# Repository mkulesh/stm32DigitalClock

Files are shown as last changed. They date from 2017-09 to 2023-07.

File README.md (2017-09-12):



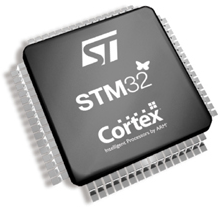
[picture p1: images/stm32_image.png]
#  "A digital clock based on STM32F405 MCU"

This repository provides hardware layout and firmware for a radio-controlled digital clock based on [STM32F405RG](http://www.st.com/content/st_com/en/products/microcontrollers/stm32-32-bit-arm-cortex-mcus/stm32-high-performance-mcus/stm32f4-series/stm32f405-415/stm32f405rg.html) MCU and [DCF77](https://de.wikipedia.org/wiki/DCF77) receiver:
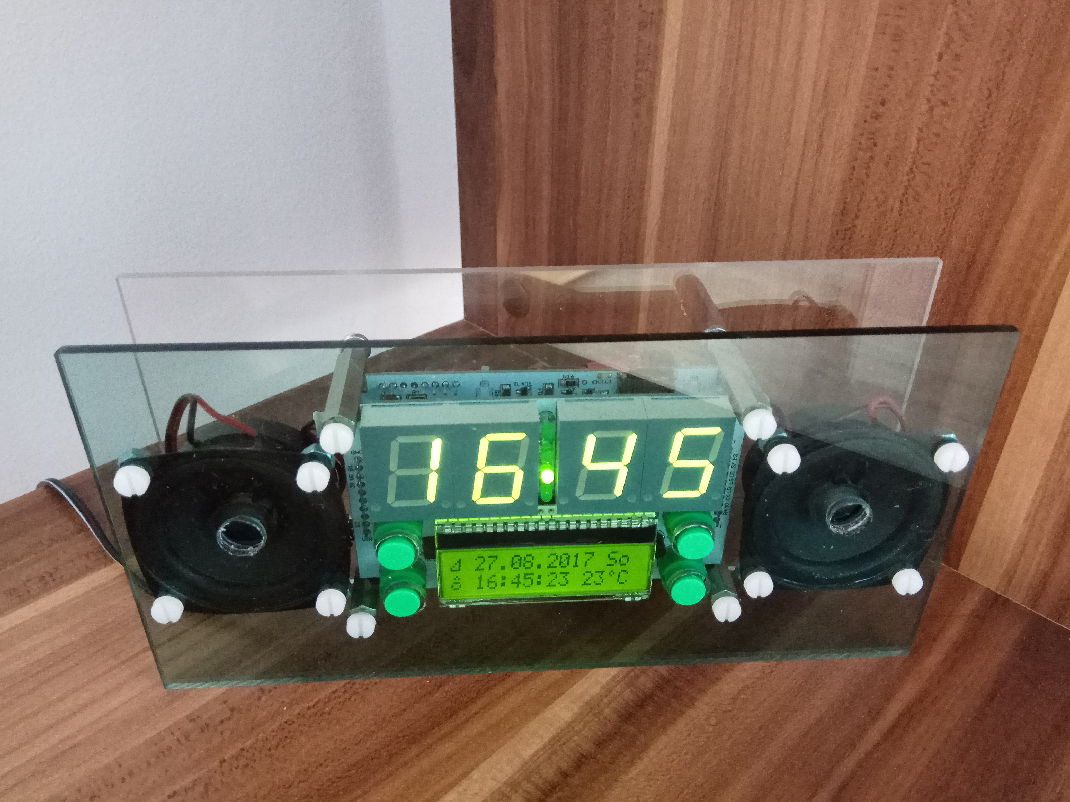
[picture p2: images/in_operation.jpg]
in operation


## Hardware design
This clock consist of two boards:
- the first display board contains four 0.8 inch. single digit numerical displays, one 2x16 chars LCD-display, and four buttons that allow to adjust current time, three alarms and some settings:
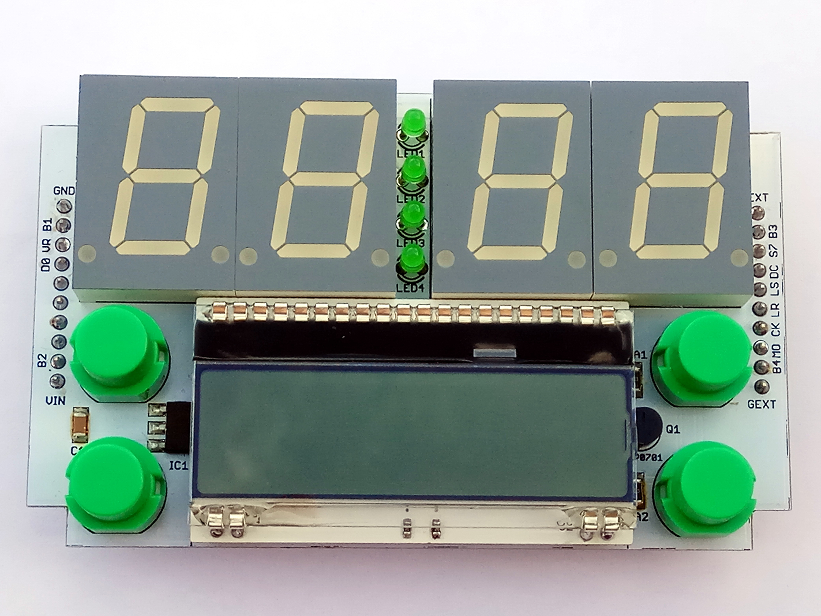
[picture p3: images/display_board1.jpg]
display board


- the second board contains STM32F405 MCU with a lot of periphery: DC connector, voltage regulators, HSE and LSE crystals, JTAG programming connector, light sensor, temperature sensor, DCF77 receiver with ferrite core, SD card connector, DAC and audio amplifier for primary WAV-based alarm, outputs for audio speakers, one piezo buzzer for the secondary alarm, UART-USB bridge and USB connector (used for debugging purposes):
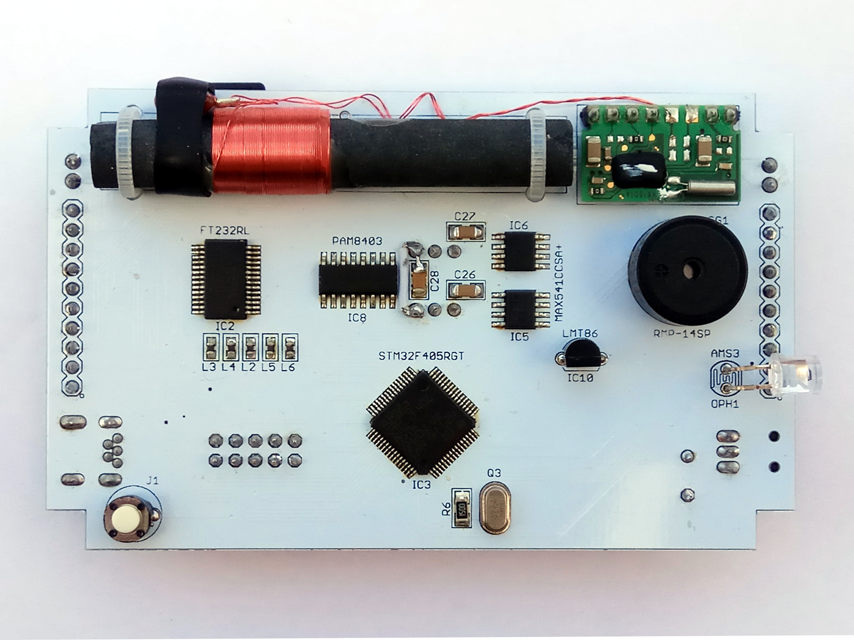
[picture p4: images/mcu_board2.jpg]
mcu board


PCB are developed in Eagle CAD (see directory pcb):
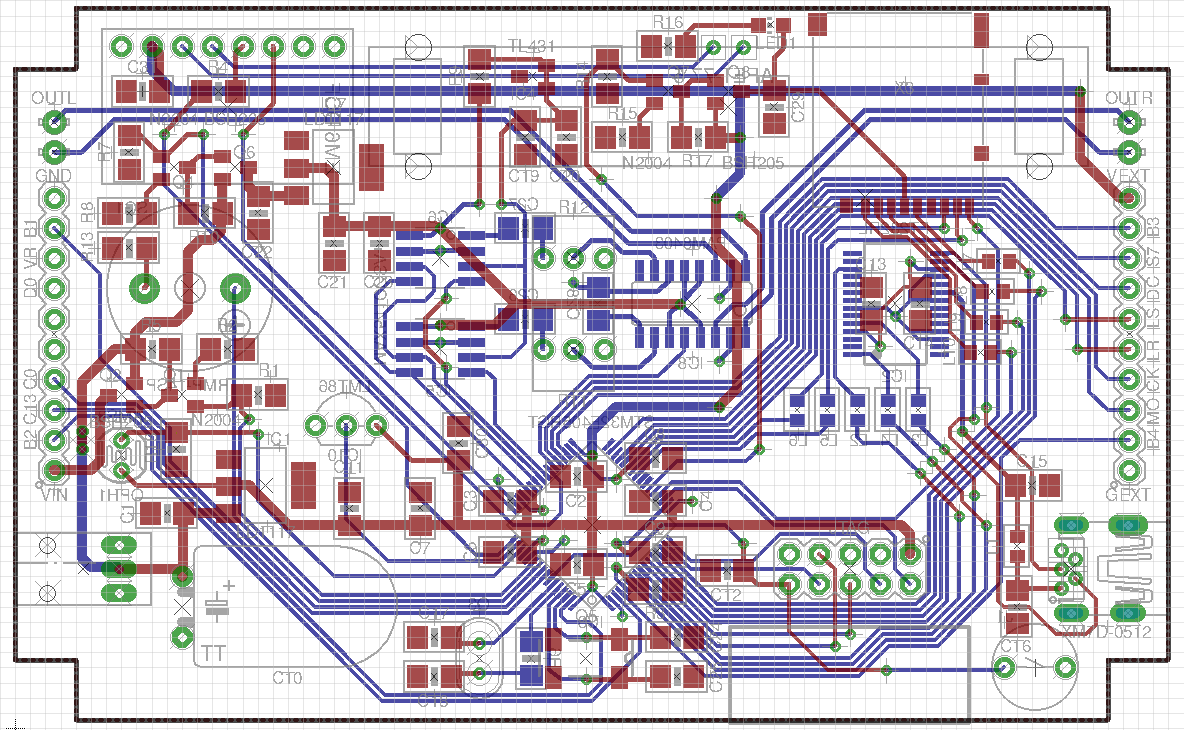
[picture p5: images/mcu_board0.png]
mcu board layout

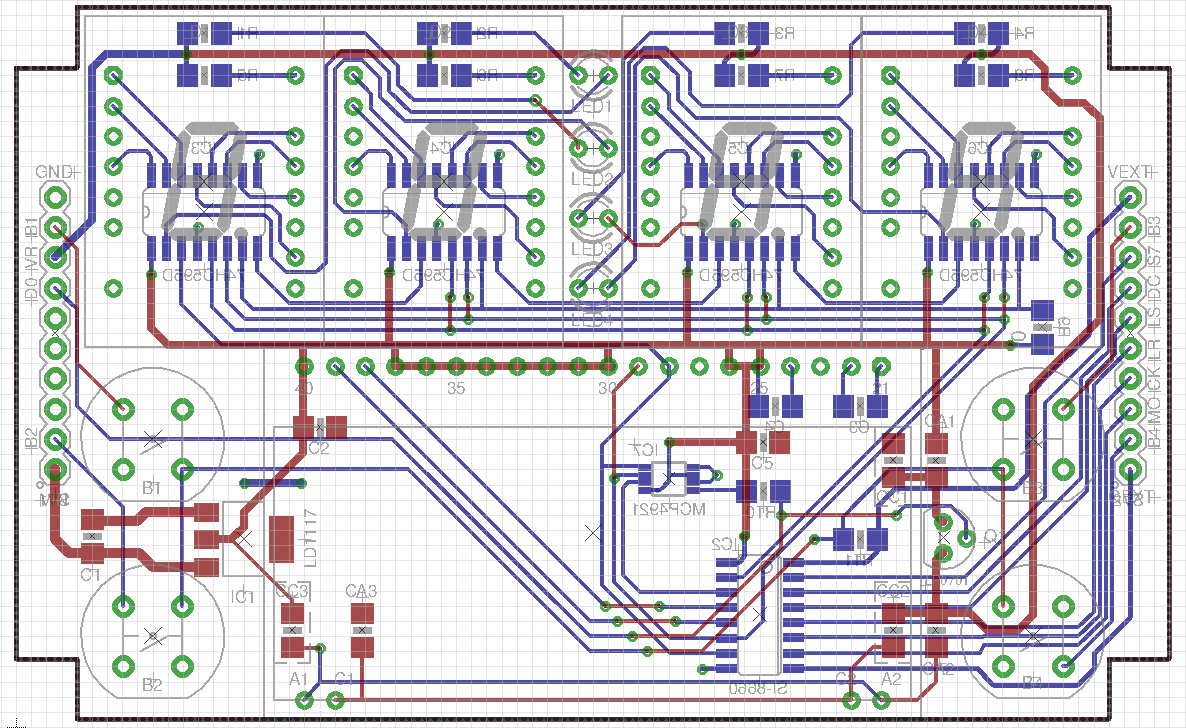
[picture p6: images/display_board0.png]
display board layout


## Firmware
The firmware (see directory src) is written in C++ [System Workbench for STM32](http://www.st.com/en/development-tools/sw4stm32.html). It is based on HAL library, FatFS and the second object-oriented abstraction layer called *StmPlusPlus* that implements high-level access for all used hardware components. *StmPlusPlus* also contains WAV-streamer (16 bit stereo, 44kHz) and [DCF77](https://de.wikipedia.org/wiki/DCF77) receiver with a special windowed filter used to improce signal quality.

## There are some known problems in this project
- DCF77 receiver heeds some time a pair of hours to capture the time stamp. 
- Wrong position of the DC and USB connector: access to the connector is blocked by audio speakers
- Level of the input signal for the audio amplifier is too high. 

## License
This software is published under the *GNU General Public License, Version 3*

Copyright (C) 2016-2017 Mikhail Kulesh

This program is free software: you can redistribute it and/or modify it under the terms of the GNU General Public License as published by the Free Software Foundation, either version 3 of the License, or (at your option) any later version.

This program is distributed in the hope that it will be useful, but WITHOUT ANY WARRANTY; without even the implied warranty of MERCHANTABILITY or FITNESS FOR A PARTICULAR PURPOSE.  See the GNU General Public License for more details. You should have received a copy of the GNU General Public License along with this program.

If not, see [www.gnu.org/licenses](http://www.gnu.org/licenses).

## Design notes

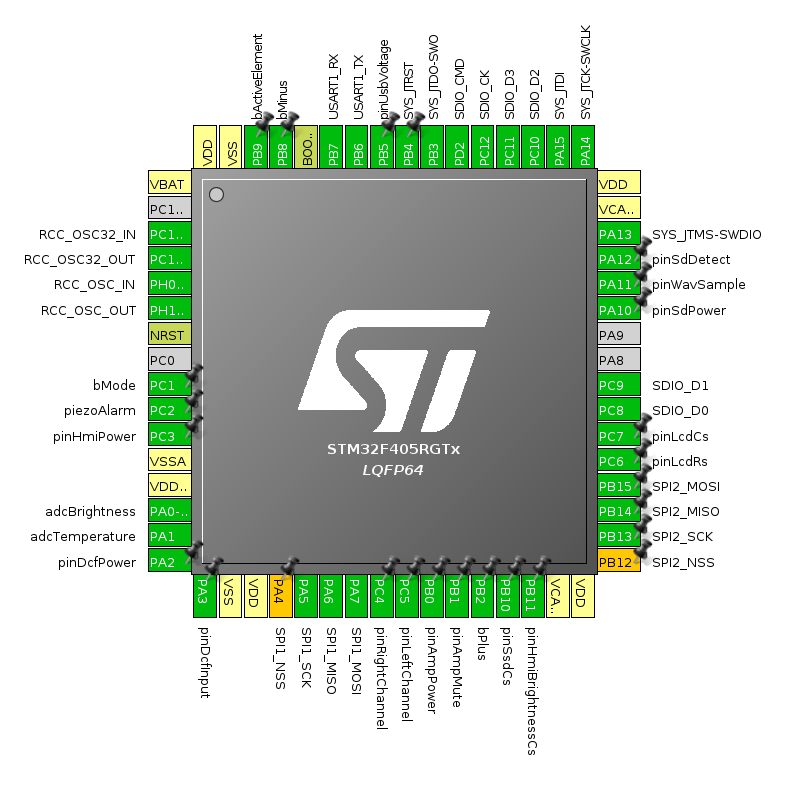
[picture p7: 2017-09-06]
images/mcu_pinout.png

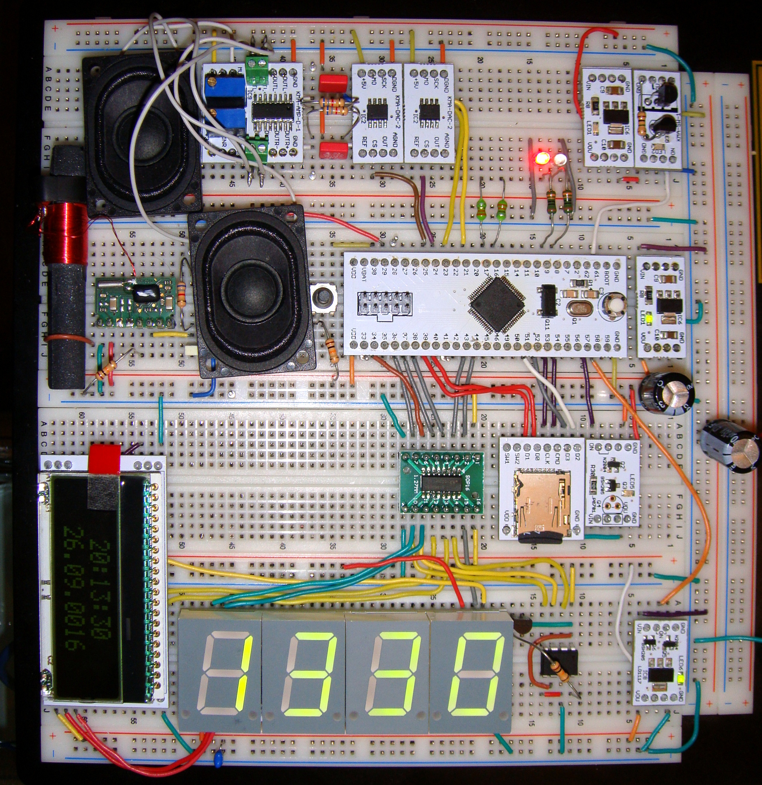
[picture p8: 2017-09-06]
images/prototype1.jpg

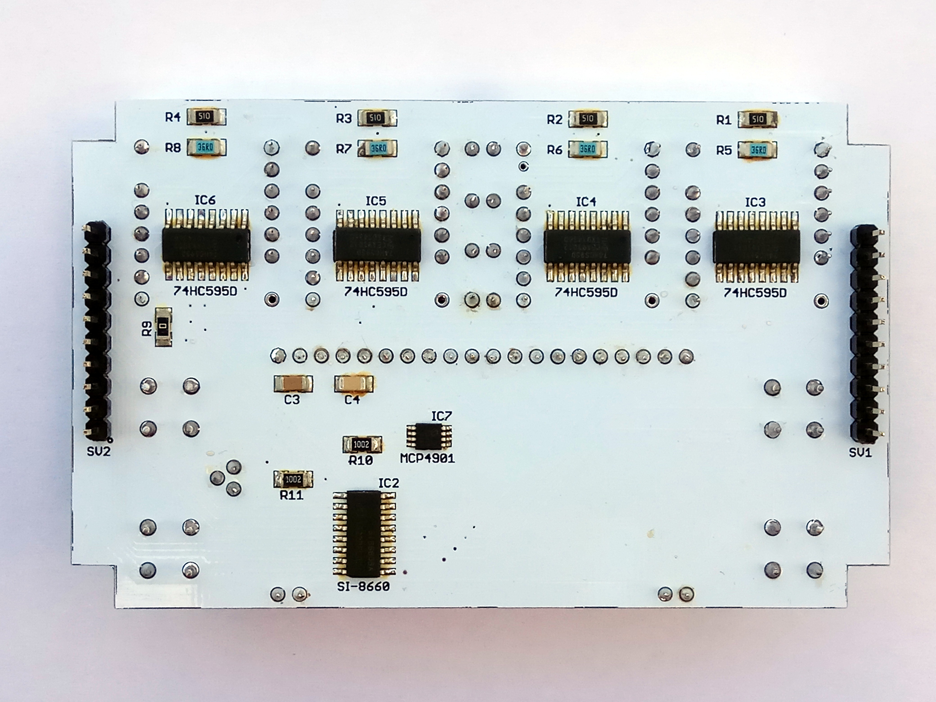
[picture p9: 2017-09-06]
images/display_board2.jpg

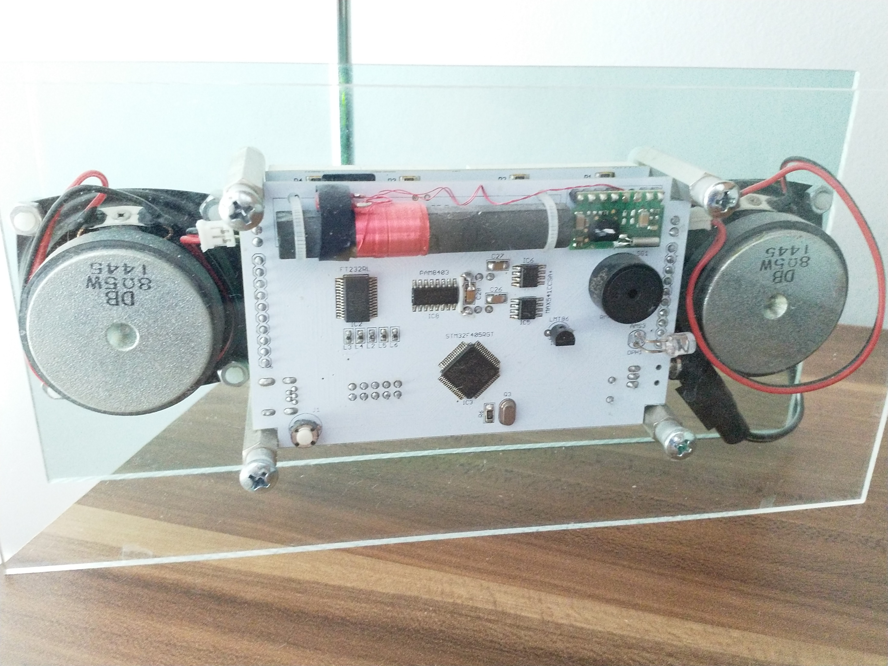
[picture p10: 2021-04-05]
images/back_view.jpg

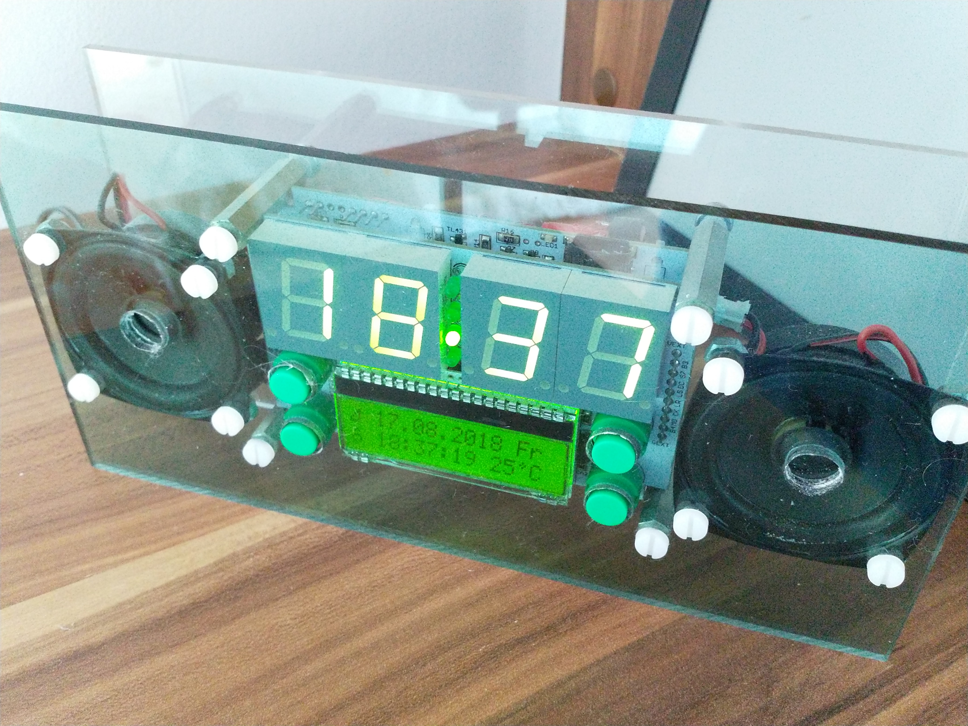
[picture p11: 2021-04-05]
images/front_view.jpg

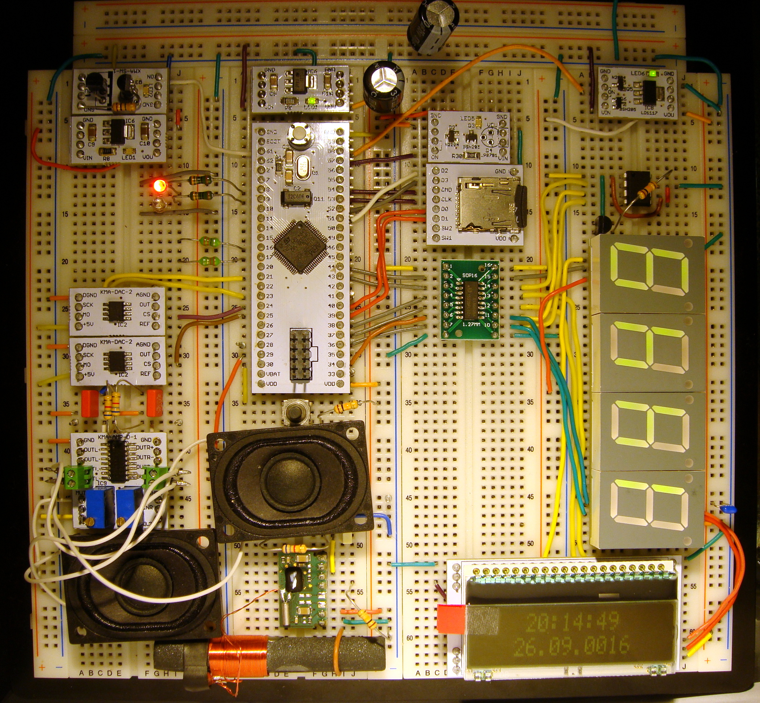
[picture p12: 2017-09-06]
images/prototype2.jpg

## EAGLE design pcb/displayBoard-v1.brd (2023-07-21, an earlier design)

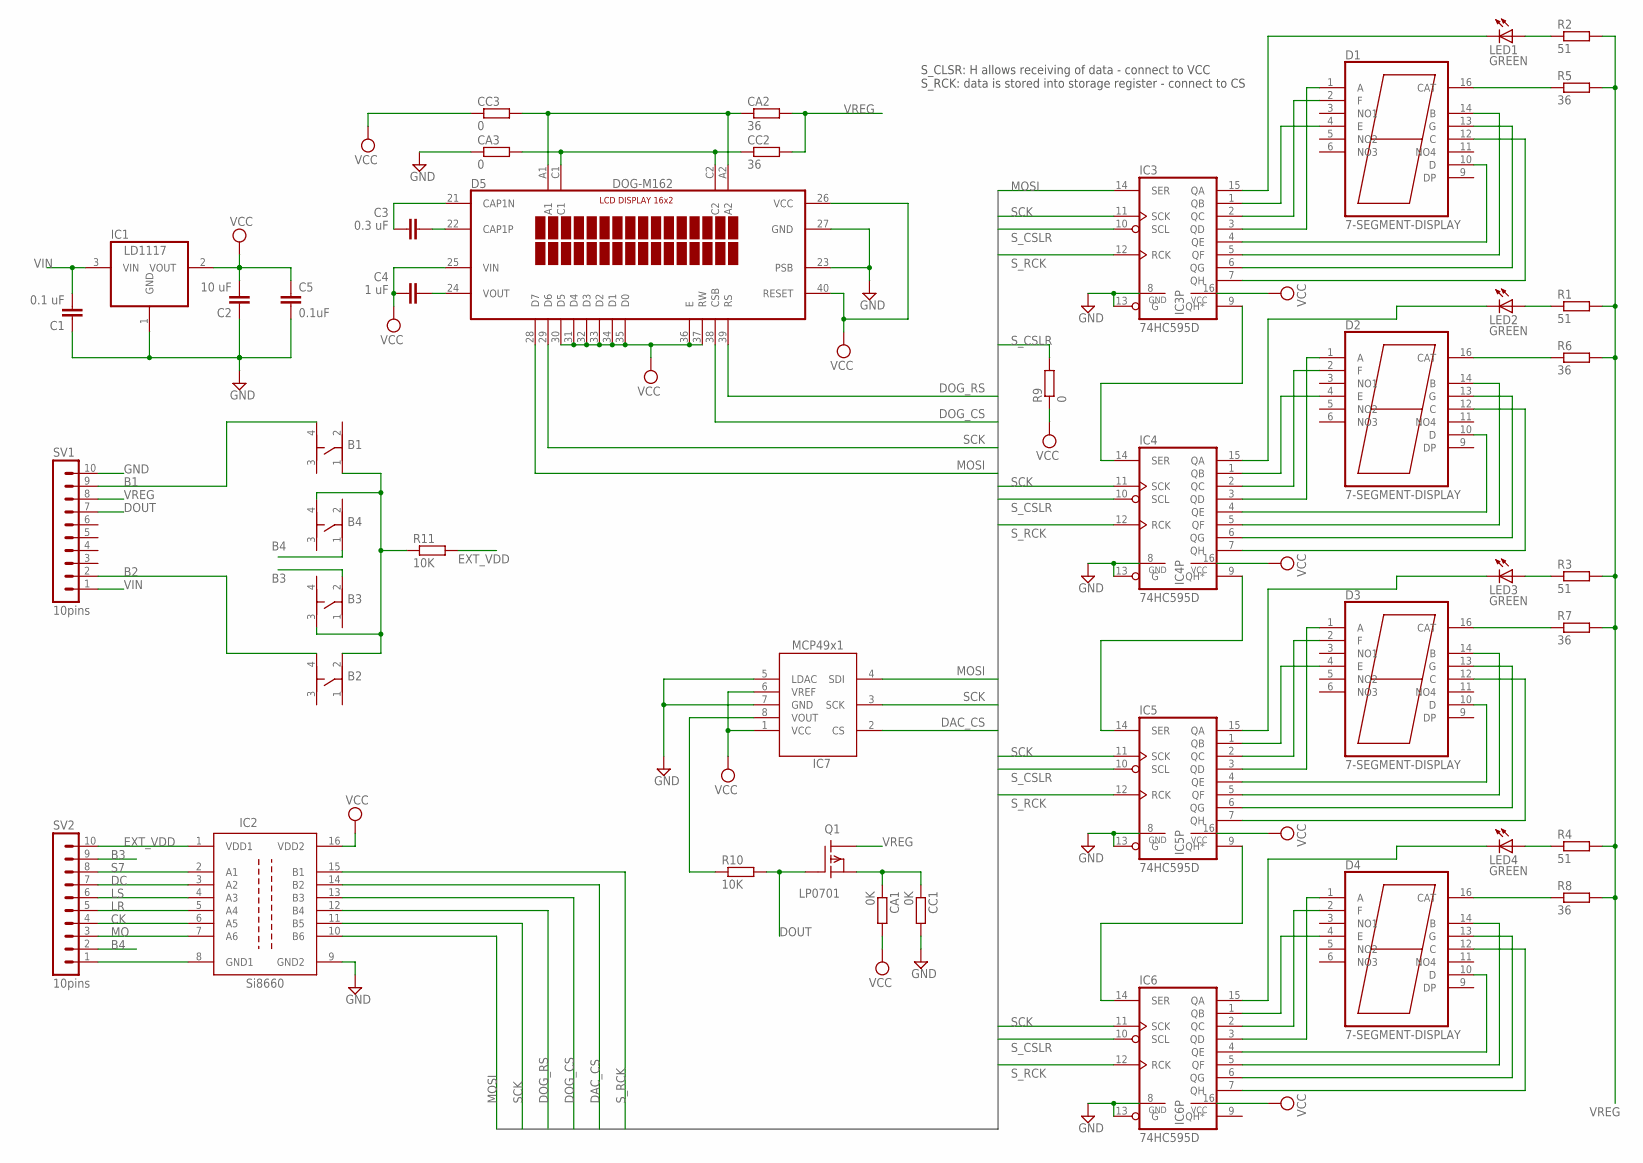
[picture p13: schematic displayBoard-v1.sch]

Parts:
B1, B2, B3, B4: BUTTON-D6X
C1: 0.1 uF; C1206
C2: 10 uF; C1206
C3: 0.3 uF; C1206
C4: 1 uF; C1206
C5: 0.1uF; C1206
CA1: 0K; R1206
CA2: 36; R1206
CA3: 0; R1206
CC1: 0K; R1206
CC2: 36; R1206
CC3: 0; R1206
D1, D2, D3, D4: 7-SEGMENT-DISPLAY; LDS-A812
D5: DOG-M162; DOGM162
IC1: LD1117; SOT223
IC2: SI-8660; SOP-16
IC3, IC4, IC5, IC6: 74HC595D; SO16
IC7: MCP4921; MSOP-8
LED1, LED2, LED3, LED4: GREEN; LED3MM
Q1: LP0701; TO-92
R1, R2, R3, R4: 51; R1206
R5, R6, R7, R8: 36; R1206
R9: 0; R1206
R10, R11: 10K; R1206
SV1, SV2: 10pins; MA10-1

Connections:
B1: B1.4, SV1.9
B2: B2.4, SV1.2
B3: B3.2, SV2.9
B4: B4.1, SV2.2
CK: IC2.6 (A5), SV2.4
DAC_CS: IC2.14 (B2), IC7.2 (CS)
DC: IC2.3 (A2), SV2.7
DOG_CS: D5.38 (CSB), IC2.13 (B3)
DOG_RS: D5.39 (RS), IC2.12 (B4)
DOUT: Q1.2 (G), R10.2, SV1.7
EXT_VDD: IC2.1 (VDD1), R11.2, SV2.10
GND: C1.1, C2.1, C5.2, CA3.1, CC1.2, D5.23 (PSB), D5.27 (GND), IC1.1 (GND), IC2.9 (GND2), IC3.8 (GND), IC3.13 (G), IC4.8 (GND), IC4.13 (G), IC5.8 (GND), IC5.13 (G), IC6.8 (GND), IC6.13 (G), IC7.5 (LDAC), IC7.7 (GND), SV1.10
LR: IC2.5 (A4), SV2.5
LS: IC2.4 (A3), SV2.6
MO: IC2.7 (A6), SV2.3
MOSI: D5.28 (D7), IC2.10 (B6), IC3.14 (SER), IC7.4 (SDI)
unnamed: D1.12 (C), IC3.7 (QH)
unnamed: D2.4 (E), IC4.1 (QB)
unnamed: D2.1 (A), IC4.3 (QD)
unnamed: D2.10 (D), IC4.4 (QE)
unnamed: D2.13 (G), IC4.6 (QG)
unnamed: D3.4 (E), IC5.1 (QB)
unnamed: D3.2 (F), IC5.2 (QC)
unnamed: D3.1 (A), IC5.3 (QD)
unnamed: D3.13 (G), IC5.6 (QG)
unnamed: D3.12 (C), IC5.7 (QH)
unnamed: D4.4 (E), IC6.1 (QB)
unnamed: IC2.8 (GND1), SV2.1
unnamed: B1.1, B2.2, B3.3, B4.4, R11.1
unnamed: LED4.A, R4.1
unnamed: LED3.A, R3.1
unnamed: IC6.15 (QA), LED4.K (C)
unnamed: IC7.8 (VOUT), R10.1
unnamed: IC5.15 (QA), LED3.K (C)
unnamed: IC4.15 (QA), LED2.K (C)
unnamed: D1.4 (E), IC3.1 (QB)
unnamed: D1.2 (F), IC3.2 (QC)
unnamed: LED2.A, R1.1
unnamed: D1.1 (A), IC3.3 (QD)
unnamed: D1.10 (D), IC3.4 (QE)
unnamed: D1.14 (B), IC3.5 (QF)
unnamed: D1.13 (G), IC3.6 (QG)
unnamed: D2.2 (F), IC4.2 (QC)
unnamed: D2.14 (B), IC4.5 (QF)
unnamed: D2.12 (C), IC4.7 (QH)
unnamed: IC3.9 (QH*), IC4.14 (SER)
unnamed: D3.10 (D), IC5.4 (QE)
unnamed: D3.14 (B), IC5.5 (QF)
unnamed: D4.2 (F), IC6.2 (QC)
unnamed: D4.1 (A), IC6.3 (QD)
unnamed: D4.10 (D), IC6.4 (QE)
unnamed: D4.14 (B), IC6.5 (QF)
unnamed: D4.13 (G), IC6.6 (QG)
unnamed: D4.12 (C), IC6.7 (QH)
unnamed: IC5.9 (QH*), IC6.14 (SER)
unnamed: IC4.9 (QH*), IC5.14 (SER)
unnamed: D1.16 (CAT), R5.1
unnamed: D2.16 (CAT), R6.1
unnamed: D3.16 (CAT), R7.1
unnamed: D4.16 (CAT), R8.1
unnamed: IC3.15 (QA), LED1.K (C)
unnamed: LED1.A, R2.1
unnamed: CA1.1, CC1.1, Q1.1 (S)
unnamed: CA2.1, CC3.2, D5.A1, D5.A2
unnamed: C3.1, D5.21 (CAP1N)
unnamed: C3.2, D5.22 (CAP1P)
unnamed: C4.1, D5.24 (VOUT)
unnamed: CA3.2, CC2.1, D5.C1, D5.C2
S7: IC2.2 (A1), SV2.8
SCK: D5.29 (D6), IC2.11 (B5), IC3.11 (SCK), IC4.11 (SCK), IC5.11 (SCK), IC6.11 (SCK), IC7.3 (SCK)
S_CSLR: IC3.10 (SCL), IC4.10 (SCL), IC5.10 (SCL), IC6.10 (SCL), R9.2
S_RCK: IC2.15 (B1), IC3.12 (RCK), IC4.12 (RCK), IC5.12 (RCK), IC6.12 (RCK)
VCC: C2.2, C4.2, C5.1, CA1.2, CC3.1, D5.25 (VIN), D5.26 (VCC), D5.30 (D5), D5.31 (D4), D5.32 (D3), D5.33 (D2), D5.34 (D1), D5.35 (D0), D5.36 (E), D5.37 (RW), D5.40 (RESET), IC1.2 (VOUT), IC2.16 (VDD2), IC3.16 (VCC), IC4.16 (VCC), IC5.16 (VCC), IC6.16 (VCC), IC7.1 (VCC), IC7.6 (VREF), R9.1
VIN: C1.2, IC1.3 (VIN), SV1.1
VREG: CA2.2, CC2.2, Q1.3 (D), R1.2, R2.2, R3.2, R4.2, R5.2, R6.2, R7.2, R8.2, SV1.8

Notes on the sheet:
S_CLSR: H allows receiving of data - connect to VCC S_RCK: data is stored into storage register - connect to CS

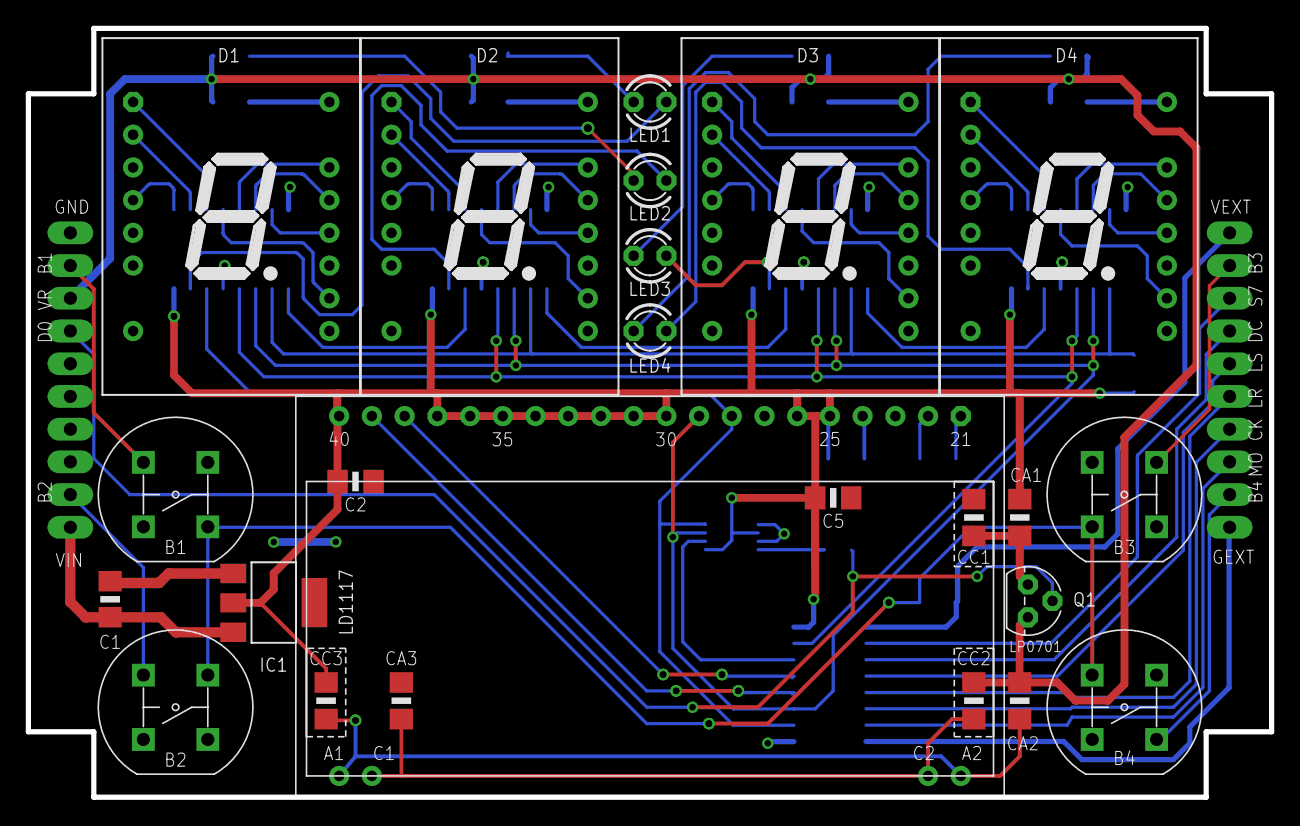
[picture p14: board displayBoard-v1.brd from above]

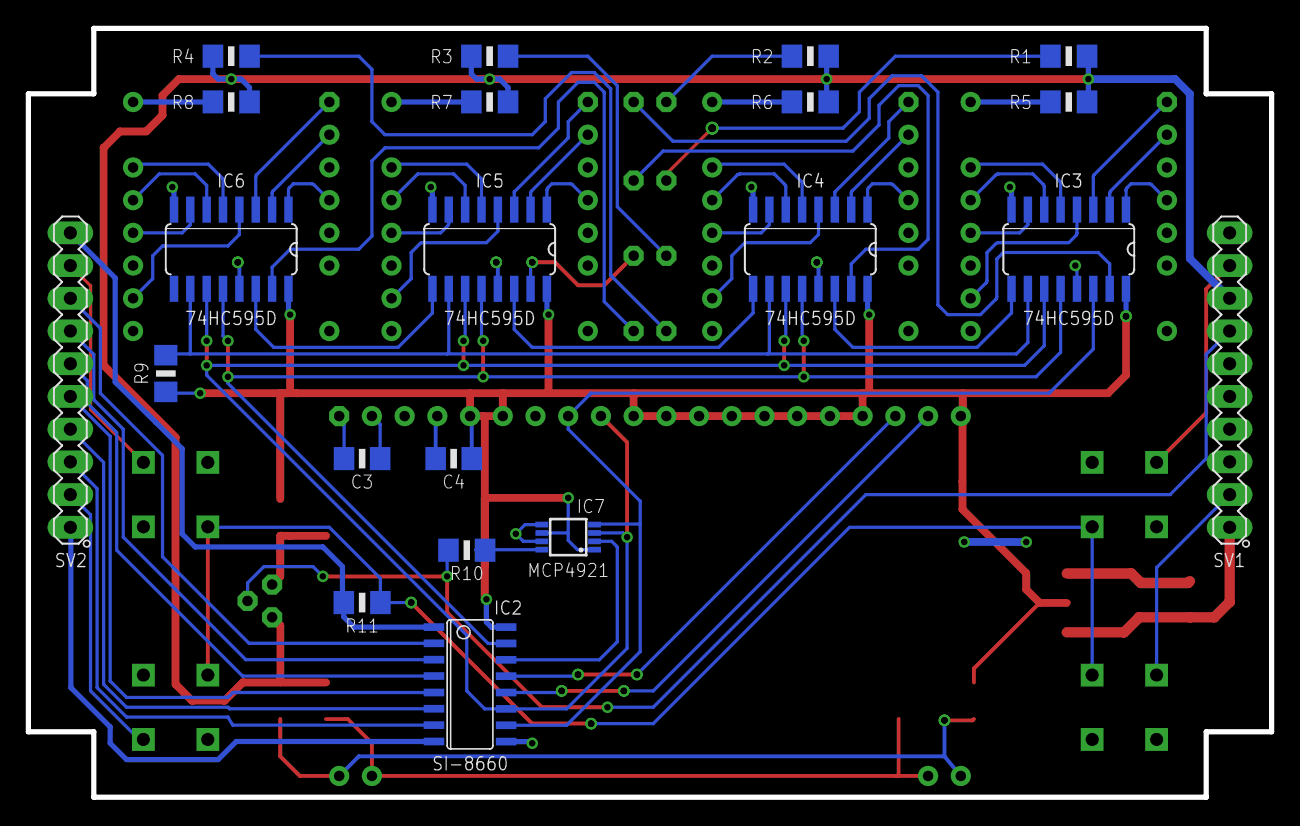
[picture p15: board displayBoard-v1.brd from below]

Board: 2 copper layers, 96.5 x 59.7 mm, 45 parts (21 on the bottom side), 75 nets.

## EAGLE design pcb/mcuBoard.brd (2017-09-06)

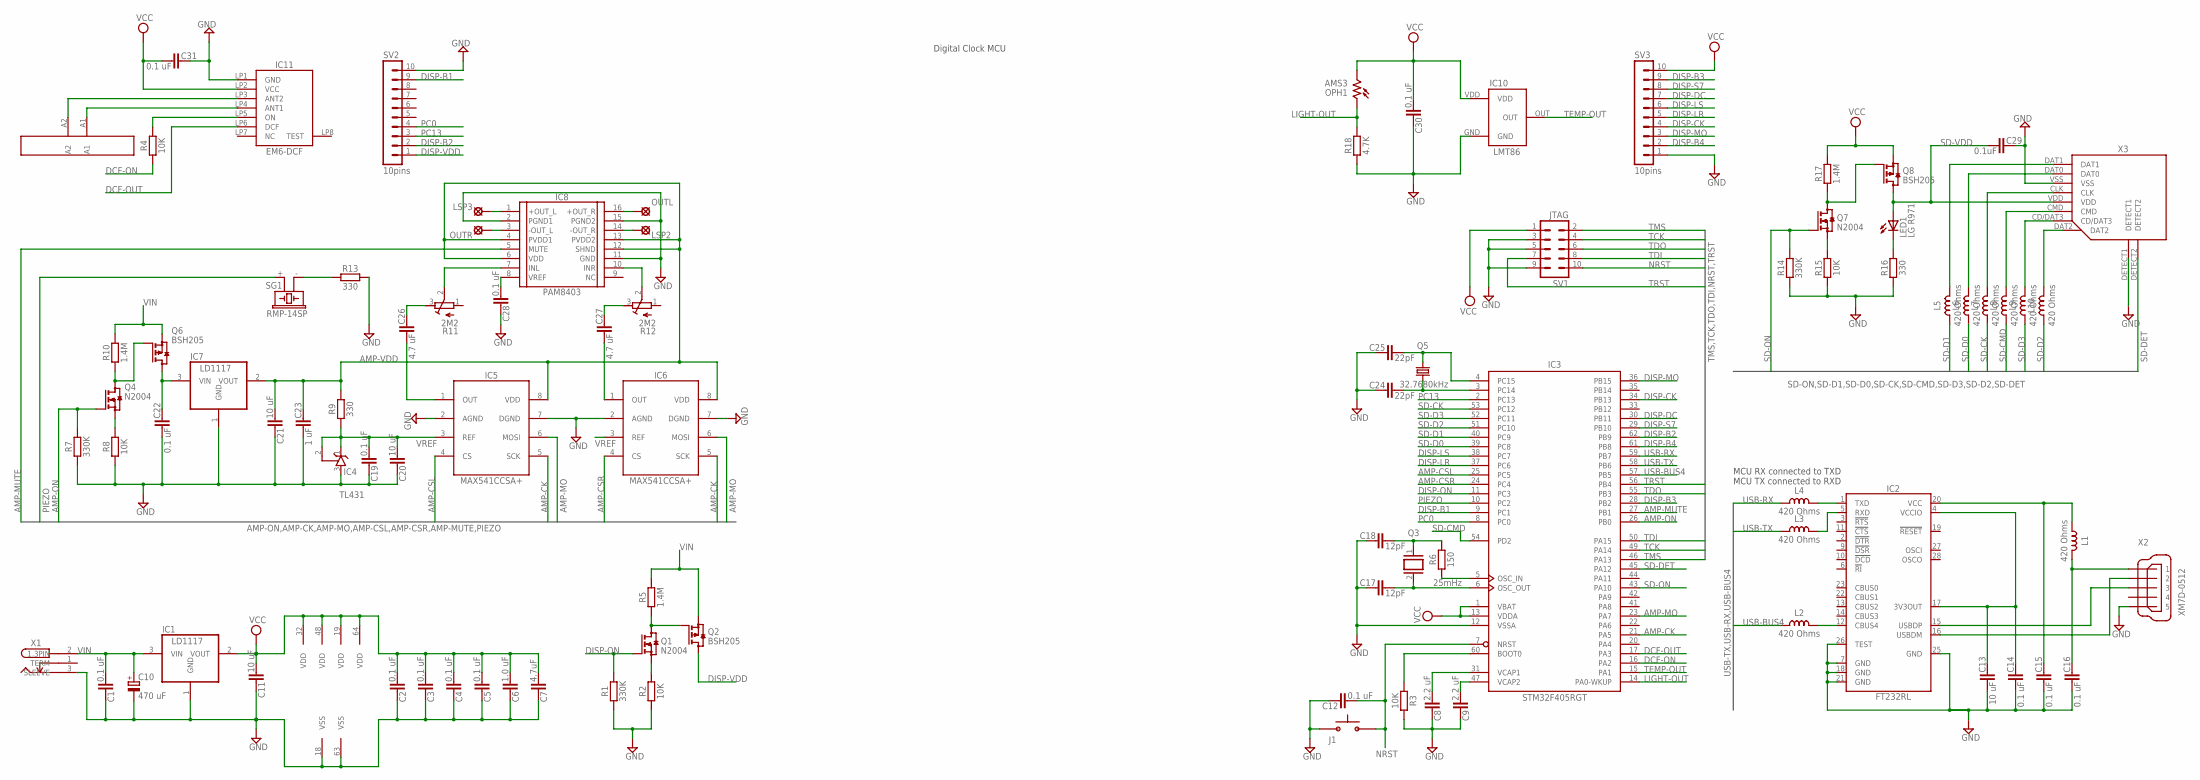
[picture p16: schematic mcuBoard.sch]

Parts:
A1: DCF77-ANT
C1, C2, C3, C4, C5, C12, C14, C15, C16, C19, C22, C28, C30, C31: 0.1 uF; C1206
C6: 1.0 uF; C1206
C7: 4.7uF; C1206
C8, C9: 2.2 uF; C1206
C10: 470 uF; TT5D11L
C11, C13, C20, C21: 10 uF; C1206
C17, C18: 12pF; C1206
C23: 1 uF; C1206
C24, C25: 22pF; C1206
C26, C27: 4.7 uF; C1206
C29: 0.1uF; C1206
IC1, IC7: LD1117; SOT223
IC2: FT232RL; SSOP28
IC3: STM32F405RGT; LQFP64
IC4: TL431; SOT-23
IC5, IC6: MAX541CCSA+; SOIC-8
IC8: PAM8403; SOP-16
IC10: LMT86
IC11: DCF77
J1: BUTTON-FSM14JRT
L1, L2, L3, L4, L5, L6, L7, L8, L9, L10: 420 Ohms; L0603
LED1: LG R971; CHIP-LED0805
LSP2, LSP3: LSP10
OPH1: AMS3; VT900
OUTL: LSP10
OUTR: LSP10
Q1, Q4, Q7: N2004; SOT23
Q2, Q6, Q8: BSH205; SOT23
Q3: 25mHz; HC-46X
Q5: 32.7680kHz; MC-306
R1, R7, R14: 330K; R1206
R2, R3, R4, R8, R15: 10K; R1206
R5, R10, R17: 1.4M; R1206
R6: 150; R1206
R9, R13, R16: 330; R1206
R11, R12: 2M2; R-TRIM-3362U
R18: 4.7K; R1206
SG1: RMP-14SP; F/CM12P
SV1: JTAG; MA05-2
SV2, SV3: 10pins; MA10-1
X1: DC-8N; BUCHSE-1.3X3.75
X2: XM7D-0512
X3: MICRO-SD-DM3AT; DM3AT

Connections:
AMP-CK: IC3.21 (PA5), IC5.5 (SCK), IC6.5 (SCK)
AMP-CSL: IC3.25 (PC5), IC5.4 (CS)
AMP-CSR: IC3.24 (PC4), IC6.4 (CS)
AMP-MO: IC3.23 (PA7), IC5.6 (MOSI), IC6.6 (MOSI)
AMP-MUTE: IC3.27 (PB1), IC8.5 (MUTE)
AMP-ON: IC3.26 (PB0), Q4.1 (G), R7.2
AMP-VDD: C21.2, C23.1, IC5.8 (VDD), IC6.8 (VDD), IC7.2 (VOUT), IC8.4 (PVDD1), IC8.6 (VDD), IC8.12 (SHND), IC8.13 (PVDD2), R9.2
BOOT: IC3.60 (BOOT0), R3.1
DAC_OUTR: C27.2, IC6.1 (OUT)
DCF-ON: IC3.16 (PA2), R4.1
DCF-OUT: IC3.17 (PA3), IC11.LP6 (DCF)
DISP-B1: IC3.9 (PC1), SV2.9
DISP-B2: IC3.62 (PB9), SV2.2
DISP-B3: IC3.28 (PB2), SV3.9
DISP-B4: IC3.61 (PB8), SV3.2
DISP-CK: IC3.34 (PB13), SV3.4
DISP-DC: IC3.30 (PB11), SV3.7
DISP-LR: IC3.37 (PC6), SV3.5
DISP-LS: IC3.38 (PC7), SV3.6
DISP-MO: IC3.36 (PB15), SV3.3
DISP-ON: IC3.11 (PC3), Q1.1 (G), R1.2
DISP-S7: IC3.29 (PB10), SV3.8
DISP-VDD: Q2.3 (D), SV2.1
D_VG: Q7.3 (D), Q8.1 (G), R17.1
D_VG1: Q4.3 (D), Q6.1 (G), R10.1
D_VG2: Q1.3 (D), Q2.1 (G), R5.1
GND: C1.1, C2.1, C3.1, C4.1, C5.1, C6.1, C7.1, C8.1, C9.1, C10.-, C11.1, C12.1, C13.2, C14.2, C15.2, C16.2, C17.1, C18.1, C19.1, C20.1, C21.1, C22.2, C23.2, C24.1, C25.1, C28.1, C29.1, C30.1, C31.1, IC1.1 (GND), IC2.7 (GND), IC2.18 (GND), IC2.21 (GND), IC2.25 (GND), IC2.26 (TEST), IC3.12 (VSSA), IC3.18 (VSS), IC3.63 (VSS), IC4.3 (A), IC5.2 (AGND), IC5.7 (DGND), IC6.2 (AGND), IC6.7 (DGND), IC7.1 (GND), IC8.2 (PGND1), IC8.11 (GND), IC8.15 (PGND2), IC10.GND, IC11.LP1 (GND), J1.P$1 (1), R1.1, R2.1, R3.2, R7.1, R8.1, R13.2, R14.1, R15.1, R16.1, R18.1, SV1.3, SV1.5, SV1.9, SV2.10, SV3.1, X1.3 (SLEEVE), X2.5, X3.DETECT1, X3.VSS
LIGHT-OUT: IC3.14 (PA0-WKUP), OPH1.1, R18.2
unnamed: IC3.5 (OSC_IN), R6.1
unnamed: A1.A1, IC11.LP4 (ANT1)
unnamed: A1.A2, IC11.LP3 (ANT2)
unnamed: L10.2, X3.DAT2
unnamed: L9.2, X3.CD/DAT3
unnamed: L8.2, X3.CMD
unnamed: L7.2, X3.CLK
unnamed: L6.2, X3.DAT0
unnamed: L5.2, X3.DAT1
unnamed: Q4.2 (S), R8.2
unnamed: C26.2, IC5.1 (OUT)
unnamed: IC8.16 (+OUT_R), OUTL.MP
unnamed: C26.1, R11.3
unnamed: C28.2, IC8.8 (VREF)
unnamed: C27.1, R12.3
unnamed: R13.1, SG1.- (2)
unnamed: C22.1, IC7.3 (VIN), Q6.3 (D)
unnamed: C16.1, L1.2, X2.1
unnamed: C15.1, IC2.20 (VCC), L1.1
unnamed: C13.1, C14.1, IC2.4 (VCCIO), IC2.17 (3V3OUT)
unnamed: IC2.16 (USBDM), X2.2
unnamed: IC2.15 (USBDP), X2.3
unnamed: IC2.1 (TXD), L4.2
unnamed: IC2.5 (RXD), L3.2
unnamed: IC2.12 (CBUS4), L2.1
unnamed: Q1.2 (S), R2.2
unnamed: C18.2, Q3.1, R6.2
unnamed: C17.2, IC3.6 (OSC_OUT), Q3.2
unnamed: IC11.LP5 (ON), R4.2
unnamed: LED1.C, R16.2
unnamed: Q7.2 (S), R15.2
unnamed: IC8.1 (+OUT_L), LSP3.MP
unnamed: IC8.3 (-OUT_L), OUTR.MP
unnamed: IC8.14 (-OUT_R), LSP2.MP
unnamed: IC8.7 (INL), R11.2
unnamed: IC8.10 (INR), R12.2
NRST: C12.2, IC3.7 (NRST), J1.P$2 (2), SV1.10
PC0: IC3.8 (PC0), SV2.4
PC13: IC3.2 (PC13), SV2.3
PIEZO: IC3.10 (PC2), SG1.+ (1)
Q2M: C24.2, IC3.3 (PC14), Q5.1
Q2P: C25.2, IC3.4 (PC15), Q5.4 (2)
SD-CK: IC3.53 (PC12), L7.1
SD-CMD: IC3.54 (PD2), L8.1
SD-D0: IC3.39 (PC8), L6.1
SD-D1: IC3.40 (PC9), L5.1
SD-D2: IC3.51 (PC10), L10.1
SD-D3: IC3.52 (PC11), L9.1
SD-DET: IC3.45 (PA12), X3.DETECT2
SD-ON: IC3.43 (PA10), Q7.1 (G), R14.2
SD-VDD: C29.2, LED1.A, Q8.3 (D), X3.VDD
TCK: IC3.49 (PA14), SV1.4
TDI: IC3.50 (PA15), SV1.8
TDO: IC3.55 (PB3), SV1.6
TEMP-OUT: IC3.15 (PA1), IC10.OUT
TMS: IC3.46 (PA13), SV1.2
TRST: IC3.56 (PB4), SV1.7
USB-BUS4: IC3.57 (PB5), L2.2
USB-RX: IC3.59 (PB7), L4.1
USB-TX: IC3.58 (PB6), L3.1
VCAP1: C8.2, IC3.31 (VCAP1)
VCAP2: C9.2, IC3.47 (VCAP2)
VCC: C2.2, C3.2, C4.2, C5.2, C6.2, C7.2, C11.2, C30.2, C31.2, IC1.2 (VOUT), IC3.1 (VBAT), IC3.13 (VDDA), IC3.19 (VDD), IC3.32 (VDD), IC3.48 (VDD), IC3.64 (VDD), IC10.VDD, IC11.LP2 (VCC), OPH1.2, Q8.2 (S), R17.2, SV1.1, SV3.10
VIN: C1.2, C10.+, IC1.3 (VIN), Q2.2 (S), Q6.2 (S), R5.2, R10.2, X1.2 (1.3PIN)
VREF: C19.2, C20.2, IC4.1 (C), IC4.2 (R), IC5.3 (REF), IC6.3 (REF), R9.1

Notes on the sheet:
MCU RX connected to TXD MCU TX connected to RXD
Digital Clock MCU

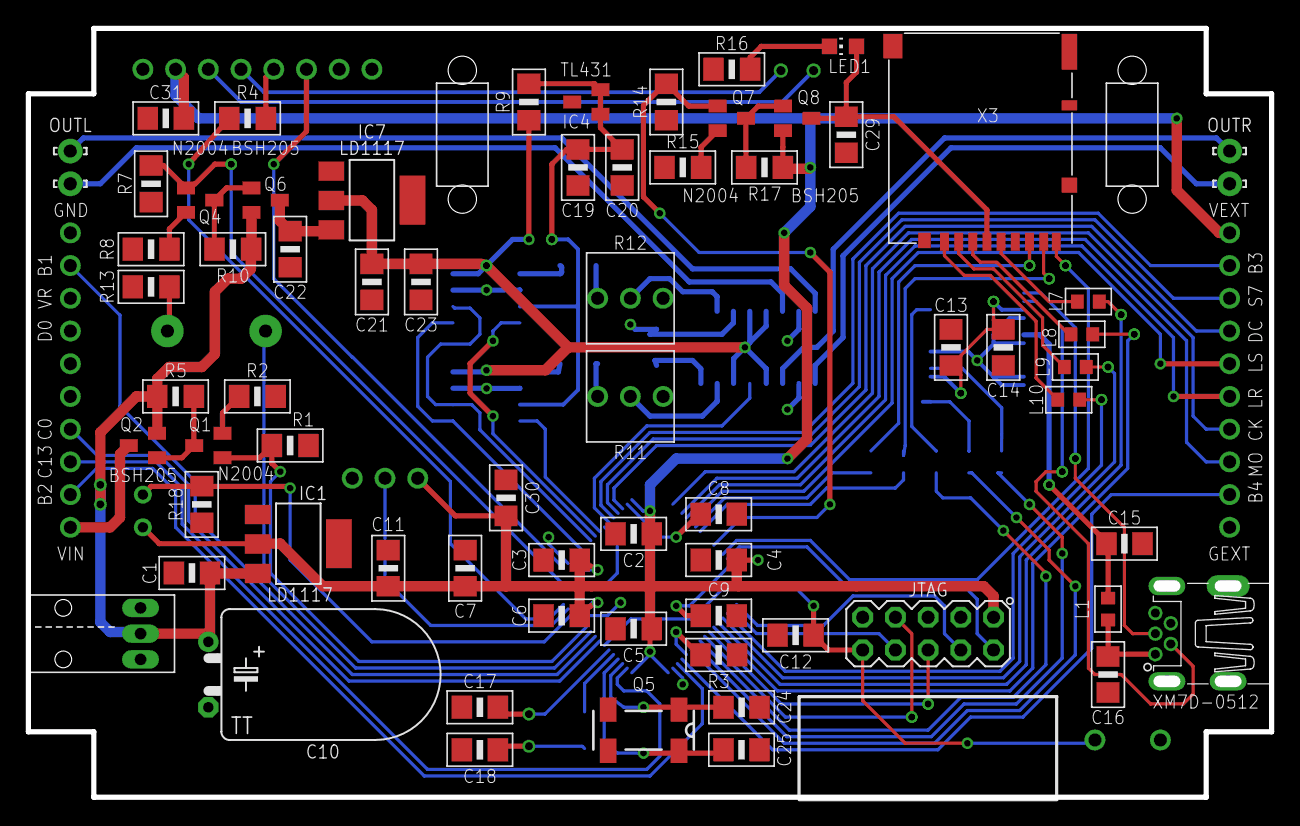
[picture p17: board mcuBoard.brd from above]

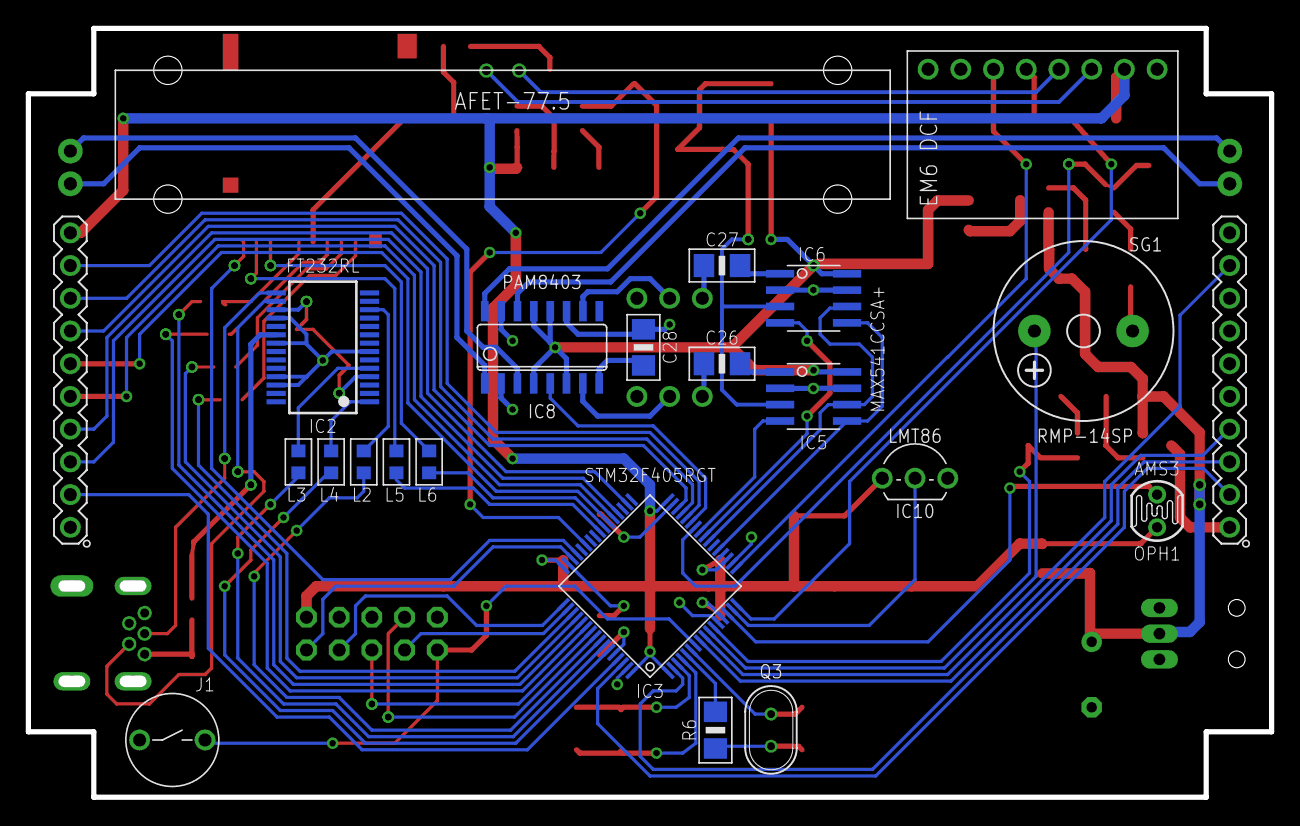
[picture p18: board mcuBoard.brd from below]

Board: 2 copper layers, 96.5 x 59.7 mm, 92 parts (23 on the bottom side), 93 nets.

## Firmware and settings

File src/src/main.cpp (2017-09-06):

/*******************************************************************************
 * stm32DigitalClock - a digital clock based on STM32F405 MCU
 * *****************************************************************************
 * Copyright (C) 2016-2017 Mikhail Kulesh
 * 
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
 * You should have received a copy of the GNU General Public License
 * along with this program.  If not, see <http://www.gnu.org/licenses/>.
 ******************************************************************************/

#include "DigitalClock.h"

DigitalClock * appPtr = NULL;
RealTimeClock * rtcPtr = NULL;

int main(void)
{
    HAL_Init();

    IOPort defaultPortA(IOPort::PortName::A, GPIO_MODE_INPUT, GPIO_PULLDOWN);
    IOPort defaultPortB(IOPort::PortName::B, GPIO_MODE_INPUT, GPIO_PULLDOWN);
    IOPort defaultPortC(IOPort::PortName::C, GPIO_MODE_INPUT, GPIO_PULLDOWN);

    do
    {
        System::setClock(25, 200, FLASH_LATENCY_5, System::RtcType::RTC_EXT, 170);
    }
    while (System::getMcuFreq() != 100000000L);

    DigitalClock app;
    appPtr = &app;
    rtcPtr = appPtr->getRtc();
    app.run();
}

extern "C" void SysTick_Handler(void)
{
    rtcPtr->onMilliSecondInterrupt();
}

extern "C" void TIM3_IRQHandler()
{
    appPtr->onTim3Interrupt();
}


extern "C" void TIM4_IRQHandler()
{
    appPtr->onTim4Interrupt();
}

extern "C" void RTC_WKUP_IRQHandler()
{
    rtcPtr->onSecondInterrupt();
}

extern "C" void DMA2_Stream3_IRQHandler(void)
{
    Devices::SdCard::getInstance()->processDmaRxInterrupt();
}

extern "C" void DMA2_Stream6_IRQHandler(void)
{
    Devices::SdCard::getInstance()->processDmaTxInterrupt();
}

extern "C" void SDIO_IRQHandler(void)
{
    Devices::SdCard::getInstance()->processSdIOInterrupt();
}

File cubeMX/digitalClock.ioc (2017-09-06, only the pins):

Mcu.UserName=STM32F405RGTx
PA0-WKUP.GPIO_Label=adcBrightness
PA0-WKUP.Signal=ADCx_IN0
PA1.GPIO_Label=adcTemperature
PA1.Signal=ADCx_IN1
PA10.GPIO_Label=pinSdPower
PA10.Signal=GPIO_Output
PA11.GPIO_Label=pinWavSample
PA11.Signal=GPIO_Output
PA12.GPIO_Label=pinSdDetect
PA12.Signal=GPIO_Input
PA13.Signal=SYS_JTMS-SWDIO
PA14.Signal=SYS_JTCK-SWCLK
PA15.Signal=SYS_JTDI
PA2.GPIO_Label=pinDcfPower
PA2.Signal=GPIO_Output
PA3.GPIO_Label=pinDcfInput
PA3.Signal=GPIO_Input
PA4.Signal=SPI1_NSS
PA5.Signal=SPI1_SCK
PA6.Signal=SPI1_MISO
PA7.Signal=SPI1_MOSI
PB0.GPIO_Label=pinAmpPower
PB0.Signal=GPIO_Output
PB1.GPIO_Label=pinAmpMute
PB1.Signal=GPIO_Output
PB10.GPIO_Label=pinSsdCs
PB10.Signal=GPIO_Output
PB11.GPIO_Label=pinHmiBrightnessCs
PB11.Signal=GPIO_Output
PB12.Signal=SPI2_NSS
PB13.Signal=SPI2_SCK
PB14.Signal=SPI2_MISO
PB15.Signal=SPI2_MOSI
PB2.GPIO_Label=bPlus
PB2.Signal=GPIO_Input
PB3.Signal=SYS_JTDO-SWO
PB4.Signal=SYS_JTRST
PB5.GPIO_Label=pinUsbVoltage
PB5.Signal=GPIO_Input
PB6.Signal=USART1_TX
PB7.Signal=USART1_RX
PB8.GPIO_Label=bMinus
PB8.Signal=GPIO_Output
PB9.GPIO_Label=bActiveElement
PB9.Signal=GPIO_Input
PC1.GPIO_Label=bMode
PC1.Signal=GPIO_Input
PC10.Signal=SDIO_D2
PC11.Signal=SDIO_D3
PC12.Signal=SDIO_CK
PC14-OSC32_IN.Signal=RCC_OSC32_IN
PC15-OSC32_OUT.Signal=RCC_OSC32_OUT
PC2.GPIO_Label=piezoAlarm
PC2.Signal=GPIO_Output
PC3.GPIO_Label=pinHmiPower
PC3.Signal=GPIO_Output
PC4.GPIO_Label=pinRightChannel
PC4.Signal=GPIO_Output
PC5.GPIO_Label=pinLeftChannel
PC5.Signal=GPIO_Output
PC6.GPIO_Label=pinLcdRs
PC6.Signal=GPIO_Output
PC7.GPIO_Label=pinLcdCs
PC7.Signal=GPIO_Output
PC8.Signal=SDIO_D0
PC9.Signal=SDIO_D1
PD2.Signal=SDIO_CMD
PH0-OSC_IN.Signal=RCC_OSC_IN
PH1-OSC_OUT.Signal=RCC_OSC_OUT

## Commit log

2019-04-28 Updated PCB description
2023-07-21 Added description
    [displayBoard-v1.brd, displayBoard-v1.sch, displayBoard-v2.brd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]

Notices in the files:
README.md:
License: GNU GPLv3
